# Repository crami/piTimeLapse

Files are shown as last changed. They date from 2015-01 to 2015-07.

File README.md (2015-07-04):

# piTimeLapse

piTimeLapse is a program to run on a Raspberry PI and a piTFT display module with some additional
electronics to drive a stepper motor and control a DSLR camera to produce moving time lapse movies.

This is work in progress and not yet working in any way!

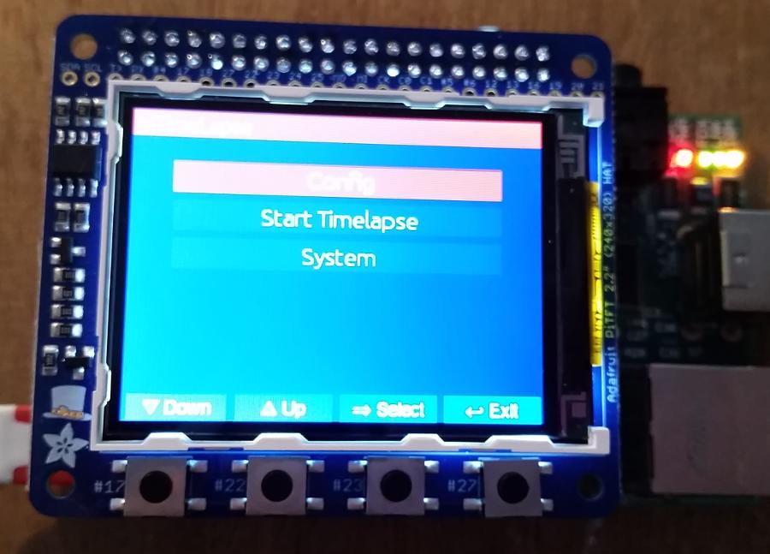
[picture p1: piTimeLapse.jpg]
Image of piTimeLapse


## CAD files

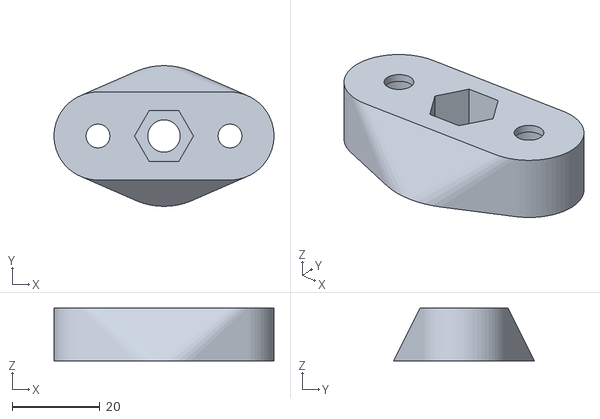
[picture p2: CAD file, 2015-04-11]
parts/tripodMount.stl
50.0 x 32.0 x 12.0

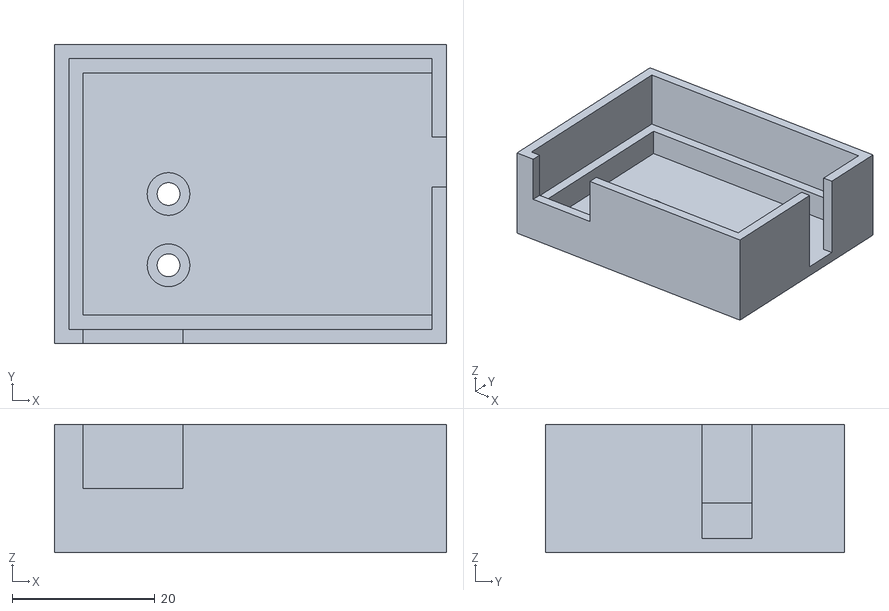
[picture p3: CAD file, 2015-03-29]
parts/PowerCaseBottom.stl
55.0 x 42.0 x 18.0

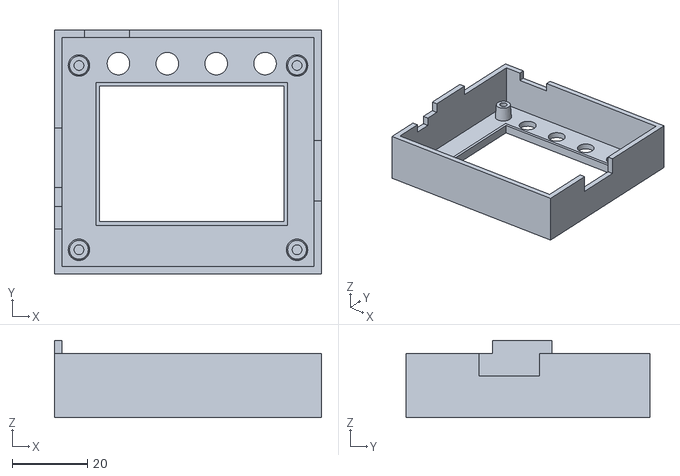
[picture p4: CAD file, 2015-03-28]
parts/caseTop.stl
71.0 x 65.0 x 20.5

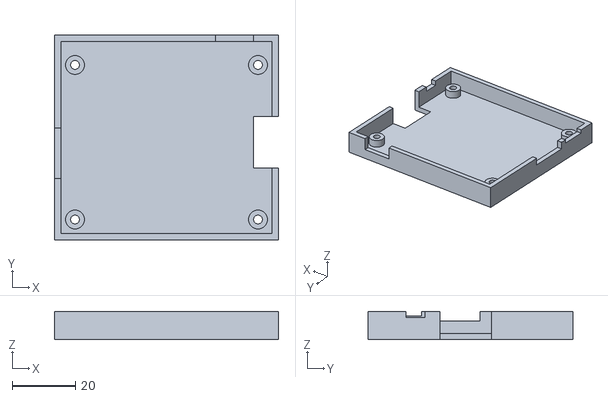
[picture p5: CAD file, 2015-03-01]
parts/caseBottom.stl
71.0 x 65.0 x 9.00

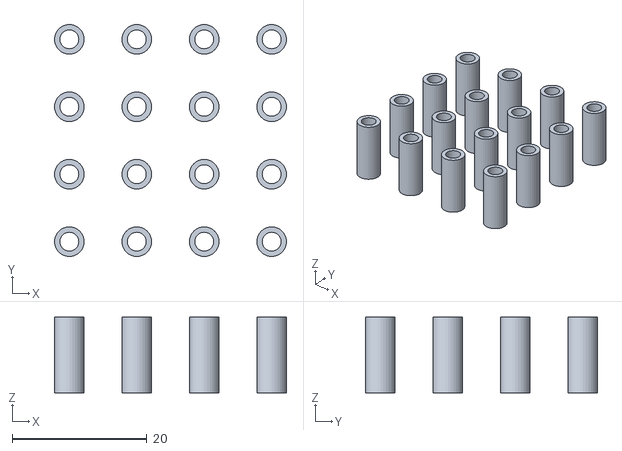
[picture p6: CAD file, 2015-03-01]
parts/DistanceTubeSmall.stl
34.4 x 34.4 x 11.2

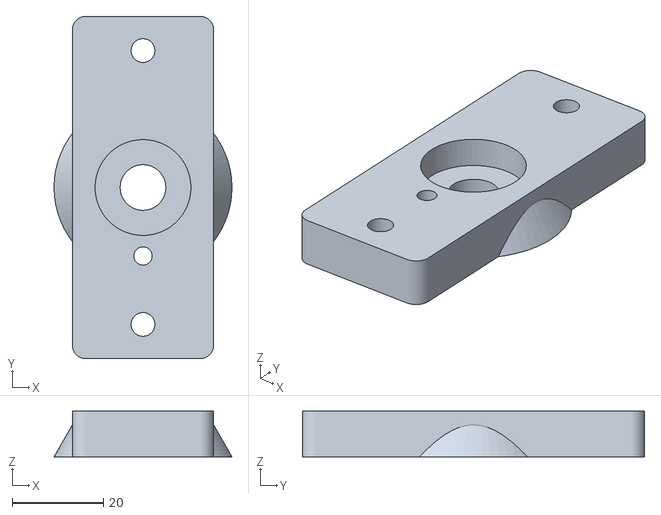
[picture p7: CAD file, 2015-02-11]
parts/BallHeadMount.stl
39.0 x 75.0 x 10.0

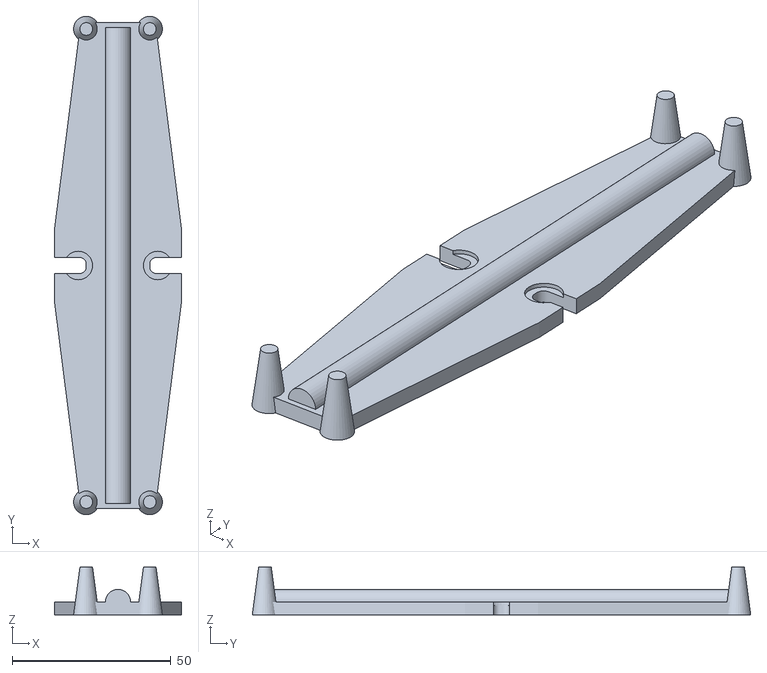
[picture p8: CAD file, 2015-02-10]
parts/feets.stl
40.0 x 157.0 x 15.0

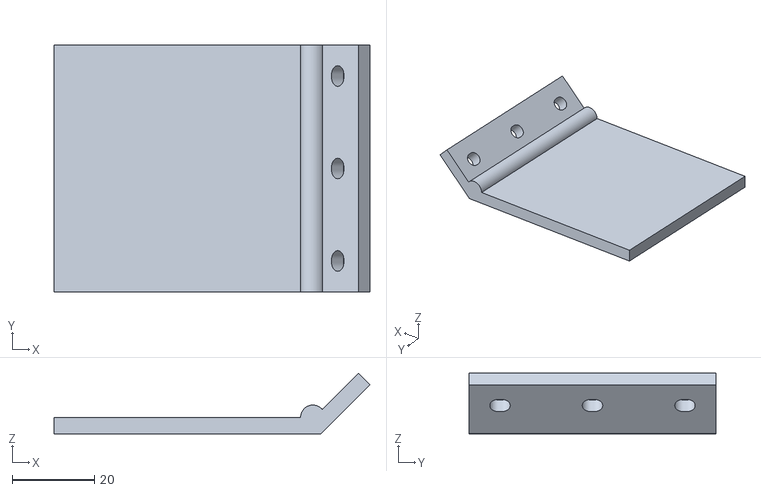
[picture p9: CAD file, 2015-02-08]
parts/piHolder.stl
76.9 x 60.0 x 14.7

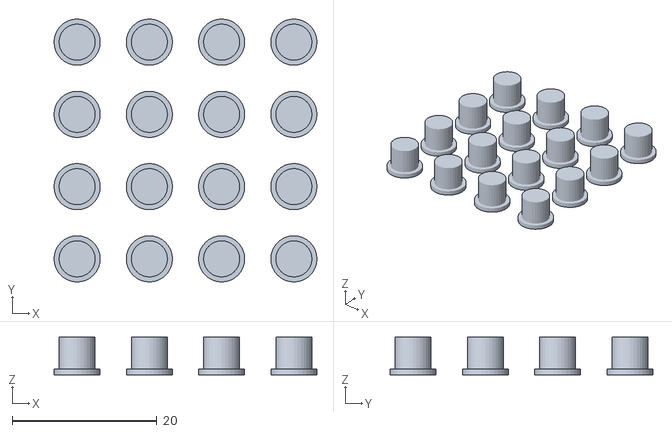
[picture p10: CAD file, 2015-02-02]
parts/PushButton.stl
36.4 x 36.4 x 5.20

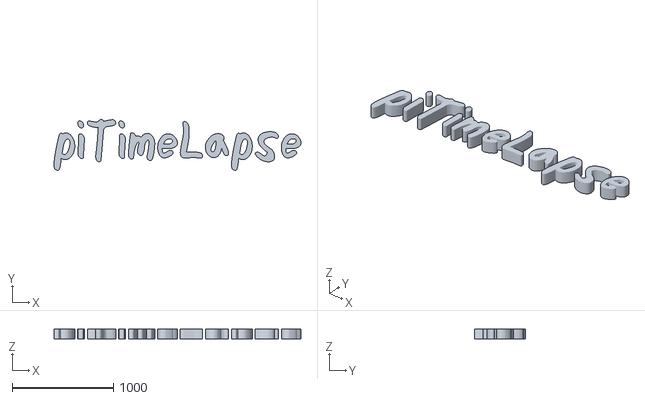
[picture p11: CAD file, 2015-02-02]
parts/piTimeLapse.stl
2440.4 x 507.0 x 100.0

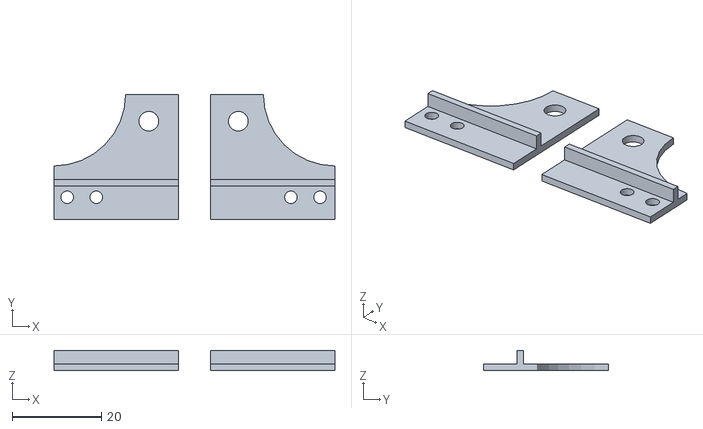
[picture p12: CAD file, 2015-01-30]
parts/EndStopSwitch.stl
62.8 x 28.0 x 4.50

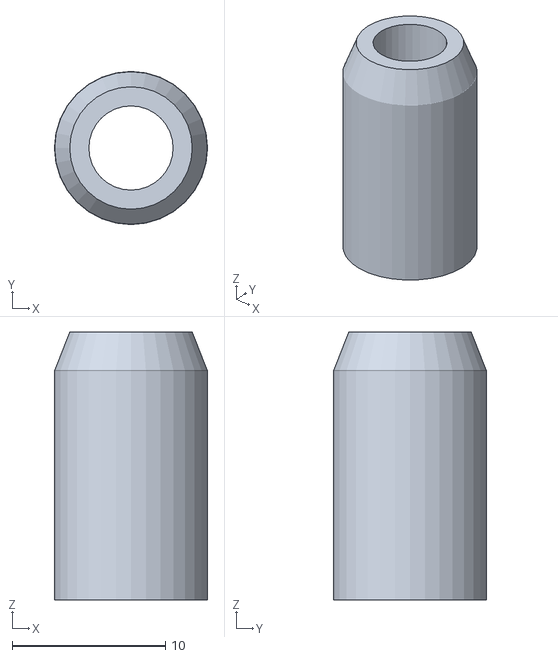
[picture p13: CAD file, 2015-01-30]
parts/EndStopCarrige.stl
10.0 x 10.0 x 17.5

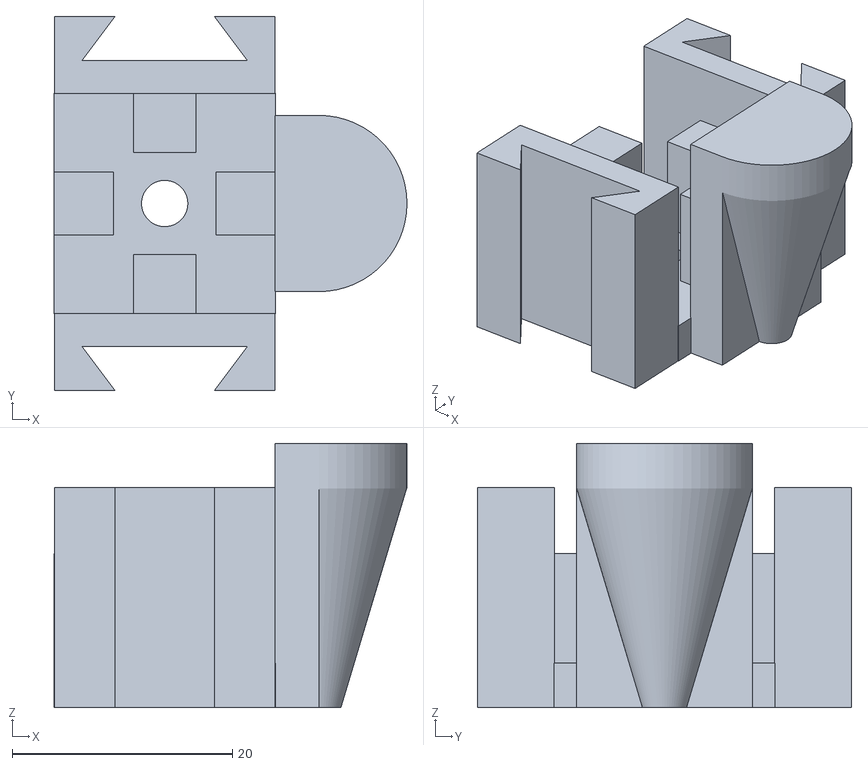
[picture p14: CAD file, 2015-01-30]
parts/EndStop.stl
32.0 x 34.0 x 24.0

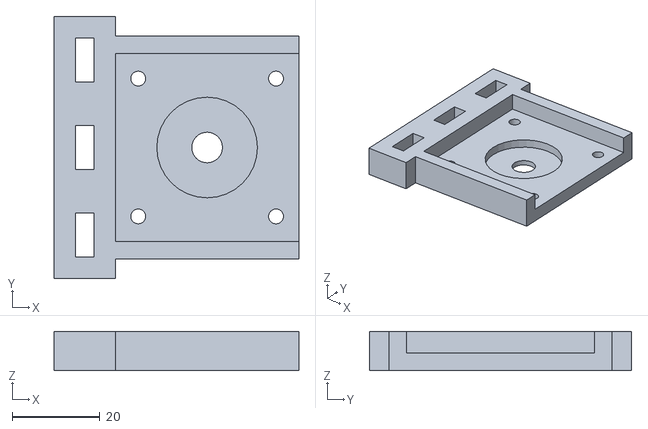
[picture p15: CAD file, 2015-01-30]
parts/MotorMount.stl
56.0 x 60.0 x 9.00

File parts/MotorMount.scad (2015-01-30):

$fn=32;

difference() {
  translate([-35,-21,0])
  difference() {
    union() {
      translate([0,-0.5,0]) cube([56,43,4]);
      translate([0,0-9,0]) cube([14,60,9]);
    }


    union() {
      translate([35,21,-0.5]) cylinder(5,3.5,3.5);
      translate([35,21,1.5]) cylinder(3,11.5,11.5);
    }
  }

  translate([15.75,15.75,-0.5]) cylinder(5,1.7,1.7);
  translate([-15.75,15.75,-0.5]) cylinder(5,1.7,1.7);
  translate([15.75,-15.75,-0.5]) cylinder(5,1.7,1.7);
  translate([-15.75,-15.75,-0.5]) cylinder(5,1.7,1.7);

  translate([-30.1,-25,-0.5]) cube([4.2,10,10]);
  translate([-30.1,-5,-0.5]) cube([4.2,10,10]);
  translate([-30.1,15,-0.5]) cube([4.2,10,10]);

}

translate([-25,-25.45,0]) cube([46,4,9]);
translate([-25,+21.45,0]) cube([46,4,9]);

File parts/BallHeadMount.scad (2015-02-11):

$fn=64;

difference() {
  union() {
    roundedcube(31,75,10,3);
    translate([15.5,37.5,0]) cylinder(7,19.5,15.5);
  }

  translate([15.5,37.5,4]) cylinder(7,10.5,10.5);
  translate([15.5,37.5,-0.5]) cylinder(11,5,5);

  translate([15.5,22.5,-0.5]) cylinder(11,2,2);

  translate([15.5,37.5+30,0]) screwhole();
  translate([15.5,37.5-30,0]) screwhole();
}

module roundedcube(x, y, z, cr) {
  hull() {
    translate([cr,cr,0]) cylinder(z,cr,cr);
    translate([x-cr,cr,0]) cylinder(z,cr,cr);
    translate([cr,y-cr,0]) cylinder(z,cr,cr);
    translate([x-cr,y-cr,0]) cylinder(z,cr,cr);
  }
}

module screwhole() {
  union() {
    translate([0,0,-0.5]) cylinder(11,2.6,2.6);
   // translate([0,0,-0.5]) cylinder(5,4.6,4.6);
   // translate([0,0,4.495]) cylinder(1,4.6,2.6);
  }
}

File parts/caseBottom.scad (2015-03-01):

height=9;

$fn=32;

module post(){
  difference() {
    translate([0,0,2]) cylinder(3,3,3);
    translate([0,0,-0.5]) cylinder(6,1.4,1.4);
  }
}

module cone() {
  union(){
    translate([0,0,-0.599]) cylinder(1,2.2,2.2);
    translate([0,0,0.4]) cylinder(2,2.2,0);
    translate([0,0,0]) cylinder(3,1.4,1.4);
  }
}

difference(){
  union(){
    cube([71,65,2]);
    cube([71,2,height]);
    cube([2,65,height]);
    translate([0,65-2,0]) cube([71,2,height]);
    translate([71-2,0,0]) cube([2,65,height]);
  }
  translate([71-8,23-0.2,-0.5]) cube([10,16.4,10]); // Micro SD
  translate([-1,19.5,6]) cube([4,16,10]); // USB
  translate([71-8-12,65-3,4]) cube([12,8,5.5]); // Power
  translate([68,12,7]) cube([4,6,4]); // Camera Jack
  translate([-1,7,7.5]) cube([4,10,2]); // Ribbon Cable

  translate([6.5,6.5,0]) cone();
  translate([6.5,65-6.5-3,0]) cone();
  translate([71-6.5,6.5,0]) cone();
  translate([71-6.5,65-6.5-3,0]) cone();


}

translate([6.5,6.5,0]) post();
translate([6.5,65-6.5-3,0]) post();
translate([71-6.5,6.5,0]) post();
translate([71-6.5,65-6.5-3,0]) post();

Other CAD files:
parts/ThumbScrewM4.stl
parts/caseTop.scad
parts/DistanceTube.scad
parts/DistanceTubeSmall.scad
parts/EndStop.scad
parts/EndStopCarrige.scad
parts/EndStopSwitch.scad
parts/PowerCaseBottom.scad
parts/PushButton.scad
parts/ThumbScrewM4.scad
parts/feets.scad
parts/piHolder.scad
parts/tripodMount.scad

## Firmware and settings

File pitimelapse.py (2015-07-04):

#!/usr/bin/python3

"""
piTimeLapse is a program to run on a Raspberry PI and a piTFT display module with some additional
electronics to drive a stepper motor and control a DSLR camera to produce moving time lapse movies.
(c) 2015 by Matthias Cramer, cramer@freestone.net
"""

import os
import sys
import pygame
import time
import socket
from subprocess import call
from pygame.locals import *
from pygame.compat import unichr_, unicode_
try:
    import RPi.GPIO as GPIO
    gpio=True
except ImportError:
    print("no GPIO module")
    gpio=False

from itertools import chain

os.environ["SDL_FBDEV"] = "/dev/fb1"
SCREEN_SIZE = (320, 240)

buttoncolor = 50,50,255
headercolor = 255,50,50
wincolor = 40, 40, 90
menucolor = [[50,50,100],[255,50,50],[50,50,50]]

pulslength=0.0035
rewindpulslength=0.0025

# Raspberry PI revision (GPIO has changed between 1 and 2)
if gpio:
    endStop = { 'Left': 12, 'Right': 13}
    camFocus=16
    camShutter=19
    motorPulse=20
    motorDir=21
    motorEna=6
    if GPIO.RPI_REVISION == 1:
#       buttonPins = [17, 22, 23, 21]
        print("This does not work on a revison 1 board, sorry!")
        exit()
    else:
        buttonPins = [17, 22, 23, 27]

movesize=0.2

buttonStateOld = [1, 1, 1, 1]

tlSet = { 'Intervall' : 10,
          'Stepsize'  : 10,
          'Direction' : 0
        }

dirList = ['Left','Right']

esState = { 'Left' : 0,
            'Right': 0
          }

tlUnits = { 'Intervall' : 's',
            'Stepsize'  : 'mm',
          }

tlPos = { 'Position'     : 0,
          'Starttime'    : 0,
          'PictureCount' : 0
        }

started = False
pause = False
posInc=0.01

# Display the splash screen
def splash():
    newScreen("")
    font = pygame.font.SysFont('matthiascramerhandwriting', 24)
    message = "Welcome to piTime"
    label = font.render(message, True, (255,255,255))
    label_rect = label.get_rect()
    label_rect.center = screen_rect.center

    # Blit image and text to the target surface.
    screen.blit(label, label_rect)
    pygame.display.flip()
    time.sleep(1)

def butondemo():
    for i in range (0, 4):
        time.sleep(0.5)
        buttonpress(i,1)
        time.sleep(1)
        buttonpress(i,0)

# Prepare a new screen
def newScreen(title):
    screen.fill(wincolor)
    if (title != ""):
        header = pygame.Rect(0, 0, screen_rect.width, 20)
        screen.fill(headercolor, header)
        font = pygame.font.SysFont('ubuntu', 16)
        label = font.render(title, True, (255,255,255))
        label_rect = label.get_rect()
        label_rect.x = 4
        label_rect.y = 2
        screen.blit(label, label_rect)

# Draw the button labels
def buttons(labels):
    btn = pygame.Rect(0, 0, screen_rect.width/4 - 6, 20)

    font = pygame.font.Font('FreeSans.ttf', 14)

    for i in range (0, 4):
        btn.x=3+((screen_rect.width/4)*i)
        btn.y=screen_rect.height-20
        screen.fill(buttoncolor, btn)
        label = font.render(labels[i], True, (255,255,255))
        label_rect = label.get_rect()
        label_rect.center = btn.center
        screen.blit(label, label_rect)

# Mark a pressed button
def buttonPress(num,toggle):
    width=(screen_rect.width/4)-6
    height=20
    x=3+((screen_rect.width/4)*num)
    y=screen_rect.height-20

    if (toggle):
        pygame.draw.polygon(screen, (255,255,255), [[x,y],[x+width,y],[x+width,y+height],[x,y+height]], 1)
    else:
        pygame.draw.polygon(screen, buttoncolor, [[x,y],[x+width,y],[x+width,y+height],[x,y+height]], 1)

        pygame.display.flip()

# Framebuffer init
def fbInit():
  disp_no = os.getenv("DISPLAY")
  if disp_no:
    print("I'm running under X display = {0}".format(disp_no))
    screen = pygame.display.set_mode(SCREEN_SIZE)
    return(screen)
  else:
    drivers = ['fbcon', 'directfb', 'svgalib']
    found = False
    for driver in drivers:
      # Make sure that SDL_VIDEODRIVER is set
      if not os.getenv('SDL_VIDEODRIVER'):
        os.putenv('SDL_VIDEODRIVER', driver)
      try:
        pygame.display.init()
      except pygame.error:
        print('Driver: {0} failed.'.format(driver))
        continue
      found = True
      break

    if not found:
      raise(Exception('No suitable video driver found!'))

    size = (pygame.display.Info().current_w, pygame.display.Info().current_h)
    print("Framebuffer size: %d x %d" % (size[0], size[1]))
    screen = pygame.display.set_mode(size, pygame.FULLSCREEN)
    return(screen)

# GPIO Init for Buttons
def gpioInit():
  GPIO.setmode(GPIO.BCM)
  GPIO.setwarnings(False)

  GPIO.setup(endStop['Left'], GPIO.IN, pull_up_down=GPIO.PUD_UP)
  GPIO.setup(endStop['Right'], GPIO.IN, pull_up_down=GPIO.PUD_UP)
  GPIO.setup(camFocus, GPIO.OUT, initial=GPIO.LOW)
  GPIO.setup(camShutter, GPIO.OUT, initial=GPIO.LOW)
  GPIO.setup(motorPulse, GPIO.OUT, initial=GPIO.LOW)
  GPIO.setup(motorDir, GPIO.OUT, initial=GPIO.LOW)
  GPIO.setup(motorEna, GPIO.OUT, initial=GPIO.HIGH)

  for i in buttonPins:
    GPIO.setup(i, GPIO.IN, pull_up_down=GPIO.PUD_UP)
    print("GPIO {0} init".format(i))

# Get Gpio Button event
def gpioGetButtons():
  buttonState = [0, 0, 0, 0]
  global buttonStateOld
  buttonevent = {"type": "none", "button": 99}

  for i in range (0,4):
    buttonState[i]=GPIO.input(buttonPins[i])
    if (buttonStateOld[i] != buttonState[i]):
#      print('Event on button {0} -> {1}'.format(buttonPins[i], buttonState[i]))
      if (buttonState[i] == 0):
        buttonevent["type"]=pygame.KEYDOWN
      if (buttonState[i] == 1):
        buttonevent["type"]=pygame.KEYUP
      buttonevent["button"]=i
      buttonPress(i,not buttonState[i])
  buttonStateOld = buttonState[:]
  return(buttonevent)


# End Program
def endProgram():
  GPIO.cleanup()
  exit()

# Get Button or Keypresses
def getButtonEvent():
  clock.tick( 10 );

  if gpio:
    buttonevent = gpioGetButtons()
    if buttonevent["type"] == pygame.KEYDOWN:
#      print("Button {0} pressed".format(buttonevent["button"]))
      return(buttonevent["button"])
#      if buttonevent["type"] == pygame.KEYUP:
#      print("Button {0} released".format(buttonevent["button"]))

  events = pygame.event.get()
  for event in events:
    button=-1
    if event.type == pygame.QUIT:
      endProgram()
    if event.type == pygame.KEYDOWN or event.type == pygame.KEYUP:
      if event.type == pygame.KEYDOWN:
        toggle=1
      if event.type == pygame.KEYUP:
        toggle=0
      if event.key == pygame.K_q:
        exit()
      if event.key == pygame.K_1:
        button=0
      if event.key == pygame.K_DOWN:
        button=0
      if event.key == pygame.K_2:
        button=1
      if event.key == pygame.K_UP:
        button=1
      if event.key == pygame.K_3:
        button=2
      if event.key == pygame.K_RETURN:
        button=2
      if event.key == pygame.K_4:
        button=3
      if event.key == pygame.K_ESCAPE:
        button=3
      buttonPress(button,toggle)
      if (toggle==1):
        return(button)

# Clear screen area
def clearScreen():
  li = pygame.Rect(0, 20, screen_rect.width, screen_rect.height-40)
  screen.fill(wincolor, li)


# Clear partial screen area
def clearTlScreen():
  li = pygame.Rect(200, 20, screen_rect.width, screen_rect.height-40)
  screen.fill(wincolor, li)


# Draw a select list menu
def drawSelectMenu(items,select):
  li = pygame.Rect(0, 0, screen_rect.width*0.8 , 24)
  font = pygame.font.SysFont('ubuntu', 18)

  for i, val in enumerate(items):

      li.x=(screen_rect.width*0.1)
      li.y=((screen_rect.height/8) * i) + 40
      screen.fill(menucolor[1 if i == select else 0], li)
      label = font.render(val, True, (255,255,255))
      label_rect = label.get_rect()
      label_rect.center = li.center
      screen.blit(label, label_rect)

  pygame.display.flip()


# Draw a settings menu
def drawSettingsMenu(settings,units,select,selected):
  li = pygame.Rect(0, 0, screen_rect.width*0.8 , 24)
  font = pygame.font.SysFont('ubuntu', 18)
  i = 0

  for key in settings:
      li.x=(screen_rect.width*0.1)
      li.y=((screen_rect.height/8) * i) + 40
      screen.fill(menucolor[1 if i == select else 0], li)
      label = font.render(key, True, (255,255,255))
      label_rect = label.get_rect()
      label_rect.center = li.center
      label_rect.x = li.x + 8
      screen.blit(label, label_rect)

      if (i == selected):
        highlight=pygame.Rect(0, 0, screen_rect.width*0.2+4 , 24)
        highlight.x=(screen_rect.width*0.7-4)
        highlight.y=((screen_rect.height/8) * i) + 40
        screen.fill(menucolor[2], highlight)

      text=""
      if key == "Direction":
        text=dirList[settings[key] % 2]
      else:
        text=str(settings[key])+" "+units[key]
      val = font.render(text, True, (255,255,255))
      val_rect = label.get_rect()
      val_rect.center = li.center
      val_rect.x = screen_rect.width*0.7
      screen.blit(val, val_rect)
      i = i + 1
      pygame.display.flip()


# Draw timelapse screen
def drawTimeLapseScreen(first,elapsed):
  global started
  global pause
  global tlPos
  font = pygame.font.SysFont('ubuntu', 22)

  line_height=30;

  if first==True:
    clearScreen()

    # Labels
    label = font.render("Position", True, (255,255,255))
    label_rect = label.get_rect()
    label_rect.x = 6
    label_rect.y = 10 + line_height
    screen.blit(label, label_rect)

    label = font.render("Picture Count", True, (255,255,255))
    label_rect = label.get_rect()
    label_rect = label.get_rect()
    label_rect.x = 6
    label_rect.y = 10 + line_height * 2
    screen.blit(label, label_rect)

    label = font.render("Time Elapsed", True, (255,255,255))
    label_rect = label.get_rect()
    label_rect = label.get_rect()
    label_rect.x = 6
    label_rect.y = 10 + line_height * 3
    screen.blit(label, label_rect)

    label = font.render("Direction", True, (255,255,255))
    label_rect = label.get_rect()
    label_rect = label.get_rect()
    label_rect.x = 6
    label_rect.y = 10 + line_height * 4
    screen.blit(label, label_rect)

  else:
    clearTlScreen()

  # Values
  label = font.render(str(tlPos['Position']), True, (255,255,255))
  label_rect = label.get_rect()
  label_rect.x = 200
  label_rect.y = 10 + line_height
  screen.blit(label, label_rect)

  label = font.render(str(tlPos['PictureCount']), True, (255,255,255))
  label_rect = label.get_rect()
  label_rect = label.get_rect()
  label_rect.x = 200
  label_rect.y = 10 + line_height * 2
  screen.blit(label, label_rect)

  tc=0
  if started==True:
      tc = time.time() - tlPos["Starttime"]
  if pause==True:
      tc = elapsed

  label = font.render("{:.1f}".format(tc) + " s", True, (255,255,255))
  label_rect = label.get_rect()
  label_rect = label.get_rect()
  label_rect.x = 200
  label_rect.y = 10 + line_height * 3
  screen.blit(label, label_rect)

  label = font.render(dirList[tlSet['Direction']], True, (255,255,255))
  label_rect = label.get_rect()
  label_rect = label.get_rect()
  label_rect.x = 200
  label_rect.y = 10 + line_height * 4
  screen.blit(label, label_rect)

  pygame.display.flip()


# Check overflow of menu selector
def checkOverflow(list, index):
  if (index < 0): index=len(list)-1
  if (index >= len(list)): index=0
  return(index)

# Main Screen
def mainScreen():
    select=0
    while(1):
        newScreen("piTimeLapse")

        btn_labels=['▼ Down','▲ Up','⇒ Select','']
        buttons(btn_labels)

        menu=["Config","Start Timelapse","System"]
        menu_f = { 0: configScreen, 1: timeLapseScreen, 2: systemScreen }

        pygame.display.flip()
        while (1):
            drawSelectMenu(menu,select)
            button=getButtonEvent()
            if button == 0:
                select=select+1
            else:
                if button == 1:
                    select=select-1
            select=checkOverflow(menu,select)
            if button == 2:
                menu_f[select]()
                break


#Config Screen
def configScreen():
  newScreen("piTimeLapse - Config")

  btn_labels=['▼ Down','▲ Up','⇒ Select','↩ Exit']
  buttons(btn_labels)

  select=0
  selected=99
  selkeys=list(tlSet.keys())

  pygame.display.flip()
  while (1):
    drawSettingsMenu(tlSet,tlUnits,select,selected)
    button=getButtonEvent()

    if button == 0:
      if selected==99:
        select=select+1
      else:
        tlSet[selkeys[select]]-=1
    else:
      if button == 1:
        if selected==99:
          select=select-1
        else:
          tlSet[selkeys[select]]+=1

    select=checkOverflow(tlSet,select)

    if button == 2:
      selected=select

    if button == 3:
      if selected==99:
        return
      else:
        selected=99

# Take an Image
def takeImage():
  global tlPos
  if gpio:
    GPIO.output(camFocus,1)
    time.sleep(0.3)
    GPIO.output(camShutter,1)
    time.sleep(0.2)
    GPIO.output(camShutter,0)
    GPIO.output(camFocus,0)
  else:
    print("Cheese")
  tlPos['PictureCount']+=1

# CallBack for Endstop
def cbEndStopEvent(pin):
  global esState

  lookup = {value: key for key, value in endStop.items()}
  value=GPIO.input(pin);
  esState[lookup[pin]]=value;

  print("{0} Endstop has changed to {1}".format(lookup[pin],value))

# Register event for endstop detection
def checkEndStop():
  global endStop
  for i in endStop:
    GPIO.add_event_detect(endStop[i], GPIO.BOTH)
    GPIO.add_event_callback(endStop[i], callback=cbEndStopEvent)

# Remove endstop events
def removeCheckEndStop():
    global esState
    global endStop
    for i in endStop:
        GPIO.remove_event_detect(endStop[i])
        esState = { 'Left' : 0,
                    'Right': 0
                  }

# Enable Stepper Motor
def motorEnable():
    GPIO.output(motorEna,0)

# Disapble Stepper Motor
def motorDisable():
    GPIO.output(motorEna,1)

# Move the camera on the rail
def moveCamera():
  global tlSet
  global tlPos
  global esState
  global started

  posold=tlPos['Position']
  tlPos['Position']+=tlSet['Stepsize']

  if (gpio):
    if (tlSet["Direction"] == 1):
      GPIO.output(motorDir,1)
    else:
      GPIO.output(motorDir,0)

    while(tlPos['Position']>=posold and esState[dirList[tlSet["Direction"]]] == 0):
      GPIO.output(motorPulse,1)
      time.sleep(pulslength)
      GPIO.output(motorPulse,0)
      time.sleep(pulslength)
      posold=posold+movesize

    if (esState[dirList[tlSet["Direction"]]] == 1):
      print("Endstop reached!")
      started=False
      esReachedScreen()
      btn_labels=['Start','','','↩ Exit']
      buttons(btn_labels)
      if gpio:
        motorDisable()
        removeCheckEndStop()
      return

  else:
    print("moveCamera")


# rewind
def rewind():
    global tlSet
    global tlPos
    global esState
    print("Rewinding")
    if (gpio):
        if (tlSet["Direction"] == 1):
            GPIO.output(motorDir,0)
        else:
            GPIO.output(motorDir,1)

        while (esState[dirList[not tlSet["Direction"]]] == 0):
            GPIO.output(motorPulse,1)
            time.sleep(rewindpulslength)
            GPIO.output(motorPulse,0)
            time.sleep(rewindpulslength)

    print("Rewinding done")
    tlPos['Position']=0
    return


# Maual Rewind
def manualRewind():
    motorEnable()
    checkEndStop()
    rewind()
    motorDisable()
    removeCheckEndStop()
    return

#TimeLapse Screen
def timeLapseScreen():
  global started
  global pause
  global tlPos
  newScreen("piTimeLapse - Time Lapse")

  btn_labels=['Start','','','↩ Exit']
  buttons(btn_labels)

  pygame.display.flip()
  lastimg=0
  first=True
  elapsed=0

  while (1):
    #print("Loop")
    drawTimeLapseScreen(first,elapsed)
    first=False
    button=getButtonEvent()
    if button == 0: # Pause/Start Button
      if started==False: # Start
        print("Start")
        if pause==False:
            tlPos["Starttime"]=time.time()
        else:
            pause=False
            tlPos["Starttime"]=time.time()-elapsed
        btn_labels[0]='Pause'
        btn_labels[1]='Stop'
        buttons(btn_labels)
        started=True
        if gpio:
          motorEnable()
          checkEndStop()
        takeImage()
        lastimg=time.time()
        moveCamera()
        if started==False:
            first=True
      else: # Pause
        if started==True:
          print("Pause")
          pause=True
          started=False
          elapsed=time.time()-tlPos["Starttime"]
          print(elapsed)
          btn_labels[0]='Start'
          buttons(btn_labels)
          if gpio:
            motorDisable();
            removeCheckEndStop()
    if button == 1:
      started=False
      pause=False
      elapsed=0
      btn_labels[0]='Start'
      btn_labels[1]=''
      buttons(btn_labels)
      rewind()
      tlPos["PictureCount"]=0
      if gpio:
        motorDisable();
        removeCheckEndStop()

    if button == 3:
      first=True
      return

    if started==True:
      print("Running...")
      if lastimg+tlSet['Intervall'] <= time.time():
        takeImage()
        lastimg=time.time()
        moveCamera()
        if started==False:
            first=True


# Get default IP address
def getDefaultIP():
    s = socket.socket(socket.AF_INET, socket.SOCK_DGRAM)
    s.connect(('8.8.8.8', 0))  # connecting to a UDP address doesn't send packets
    local_ip_address = s.getsockname()[0]

    return(local_ip_address)


# EndStop reached screen
def esReachedScreen():
  global started
  started = False
  newScreen("piTimeLapse - EndStop")

  btn_labels=['','','','↩ Exit']
  buttons(btn_labels)

  font = pygame.font.SysFont('ubuntu', 18)

  label = font.render("End stop reached!", True, (255,255,255))
  label_rect = label.get_rect()
  label_rect.center = [160,120]
  screen.blit(label, label_rect)

  pygame.display.flip()
  while (1):
    button=getButtonEvent()
    if button == 3:
      return


# The info screen
def infoScreen():
  newScreen("piTimeLapse - Info")

  btn_labels=['','','','↩ Exit']
  buttons(btn_labels)

  font = pygame.font.SysFont('ubuntu', 18)

  label = font.render("IP Address: "+getDefaultIP(), True, (255,255,255))
  label_rect = label.get_rect()
  label_rect.center = [160,120]
  screen.blit(label, label_rect)

  pygame.display.flip()
  while (1):
    button=getButtonEvent()
    if button == 3:
      return
      #systemScreen()

# The shutdown screen
def shutdownScreen():
  newScreen("piTimeLapse - Shutdown")

  btn_labels=['','Shutdown','','↩ Exit']
  buttons(btn_labels)

  font = pygame.font.SysFont('ubuntu', 18)

  label = font.render("Confirm Shutdown", True, (255,255,255))
  label_rect = label.get_rect()
  label_rect.center = [160,120]
  screen.blit(label, label_rect)

  pygame.display.flip()
  while (1):
    button=getButtonEvent()
    if button == 1:
      print("Shutdown")
      if os.getuid()==0:
        pygame.display.quit()
        call(["shutdown", "-h", "now"])
      else:
        print("Not running as root!")
    if button == 3:
      return
      #systemScreen()


#System Screen
def systemScreen():
    select=0
    while(1):
        newScreen("piTimeLapse - System")
        btn_labels=['▼ Down','▲ Up','⇒ Select','↩ Exit']
        buttons(btn_labels)

        menu=["Info","Rewind","Shutdown"]
        menu_f = { 0: infoScreen, 1: manualRewind ,2: shutdownScreen }

        pygame.display.flip()
        while (1):
            drawSelectMenu(menu,select)
            button=getButtonEvent()
            if button == 0:
                select=select+1
            else:
                if button == 1:
                    select=select-1

            select=checkOverflow(menu,select)

            if button == 2:
                menu_f[select]()
                break
            if button == 3:
                return

""" Main """

pygame.init()
screen=fbInit()
screen_rect = screen.get_rect()
pygame.mouse.set_visible(False)
pygame.display.set_caption('piTime')
clock = pygame.time.Clock()

splash()

if gpio:
  gpioInit()

while 1:
  mainScreen()

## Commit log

2015-01-14 Button draw functions
2015-01-16 Buttons now are pressable ...
2015-01-17 Framebuffer on piTFT working ...
2015-01-18 Use X Display when available for development and fall back to framebuffer on pi
2015-01-18 False has to be written correctly ... remember that
    [pitimelapse.py]
2015-01-18 First three buttons work... but why not the fourth ... pi a / a+ difference ?
2015-01-18 All buttons work now and pressing them gets displayed. pi board revision detection
2015-01-18 Bigger button font
2015-01-19 Buttonhandlig simplified
2015-01-19 swap up down ... its more intuitive
    [pitimelapse.py]
2015-01-19 slightly larger button font
2015-01-19 different button symbols
2015-01-23 increment and decrement where wrong
    [pitimelapse.py]
2015-01-25 Emty functions for cameraMove and takeImage
2015-01-30 Added 3Dprintable parts for the CameraRail ... more to come
    [DistanceTube.scad, DistanceTube.stl, EndStop.scad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]
2015-01-30 new Switch Holder
    [EndStopSwitch.scad, EndStopSwitch.stl]
2015-01-30 Buttons for the pitft 2.2" Display
    [PushButton.scad, PushButton.stl]
2015-01-30 modified push button
    [PushButton.scad, PushButton.stl]
2015-02-01 Bottom halve of pi a+ case
    [caseBottom.scad, caseBottom.stl]
2015-02-01 small corrections of usb, sdcard and power holes
    [caseBottom.scad, caseBottom.stl]
2015-02-01 small modifications to cast bottom new case top files
    [caseBottom.scad, caseBottom.stl, caseTop.scad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]
2015-02-02 corrected height and display size
    [caseTop.scad, caseTop.stl]
2015-02-02 Embossed font on case top
    [caseTop.scad, caseTop.stl, piTimeLapse.stl]
2015-02-02 slightly wider sdcard slot
    [caseBottom.scad, caseBottom.stl]
2015-02-02 new push buttons
    [PushButton.scad, PushButton.stl]
2015-02-03 Tripod Mount
    [tripodMount.scad, tripodMount.stl]
2015-02-04 define motor pins
2015-02-05 endstop detection working
2015-02-07 New Ball Head mount bigger screw hole on tripod mount
    [BallHeadMount.scad, BallHeadMount.stl, tripodMount.scad]
2015-02-08 Holder for the pi case
    [piHolder.scad, piHolder.stl]
2015-02-09 Rail feets
    [feets.scad, feets.stl]
2015-02-10 Case modificatiosn for camera plug and ribon cable longer feet
    [caseBottom.scad, caseBottom.stl, caseTop.scad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]
2015-02-11 Sturdier design with anti rotate screw hole
    [BallHeadMount.scad, BallHeadMount.stl]
2015-03-01 Distance Tubes for the piTFT inside the case
    [DistanceTubeSmall.scad, DistanceTubeSmall.stl]
2015-03-01 New Case foer power parts new screw holes removed text on case
    [PowerCaseBottom.scad, PowerCaseBottom.stl, caseBottom.scad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]
2015-03-01 First stepper test
2015-03-01 Enable / Disable Motor
2015-03-01 Initialize motorEna GPIO
2015-03-01 motorEna is inverted
2015-03-01 stepsize is 0.2mm (20 tooth pully = 40mm stepangle=1.8deg)
2015-03-01 additional structure
    [PowerCaseBottom.scad, PowerCaseBottom.stl]
2015-03-01 endstop handling
2015-03-01 Small case change
    [PowerCaseBottom.scad, PowerCaseBottom.stl]
2015-03-01 pause/stop buttons rewind function
2015-03-02 get out of loop when reaching endstop
2015-03-02 endstop value change
2015-03-02 reset picture count on stop
    [pitimelapse.py]
2015-03-02 better endstop handling
2015-03-22 Mounting hole and more space on the bottom for the screw
    [PowerCaseBottom.scad, PowerCaseBottom.stl]
2015-03-22 do not invoke menus recursively ... select color change set starttime correctly
    [pitimelapse.py]
2015-03-22 little slower wrong color
    [pitimelapse.py]
2015-03-22 Manual Rewind in System Screen Propper return from endstop reached
2015-03-28 1mm higher top fo be able to use M2.5x25mm screws tighter post holes
    [caseTop.scad, caseTop.stl]
2015-03-28 smal border around the lcd
    [caseTop.scad, caseTop.stl]
2015-03-29 second screw hole on the bottom
    [PowerCaseBottom.scad, PowerCaseBottom.stl]
2015-04-11 new tripodmount which uses a hex nut
    [tripodMount.scad, tripodMount.stl]
2015-04-11 little bit bigger holes
    [tripodMount.scad, tripodMount.stl]
2015-07-04 Code cleanup: All menus should now function propperl. no more recursive calls of functions (memory hole)
2015-07-04 Manual rewinding did not work ... should now
    [pitimelapse.py]
2015-07-04 Rewind modifications and debbug printouts
2015-07-04 reset endstop states on eventcheck removel
    [pitimelapse.py]
